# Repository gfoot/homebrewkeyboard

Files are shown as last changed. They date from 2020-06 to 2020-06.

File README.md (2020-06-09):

# George's homebrew keyboard

Schematics, board layouts, and code for adding a homebrew keyboard to your electronics projects

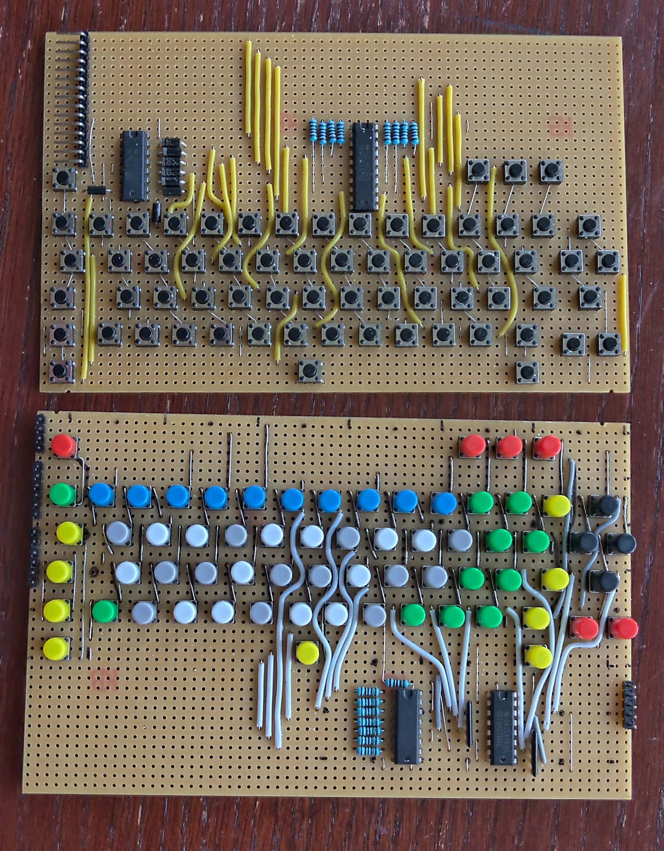
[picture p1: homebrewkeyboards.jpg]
Photograph of assembled boards


This one uses a parallel interface, ideal for connecting directly to the address and data bus of something like a 6502.

I also have one with a serial interface, more tailored for Arduino - let me know if you're interested and I'll publish it as a separate project.

# Schematic

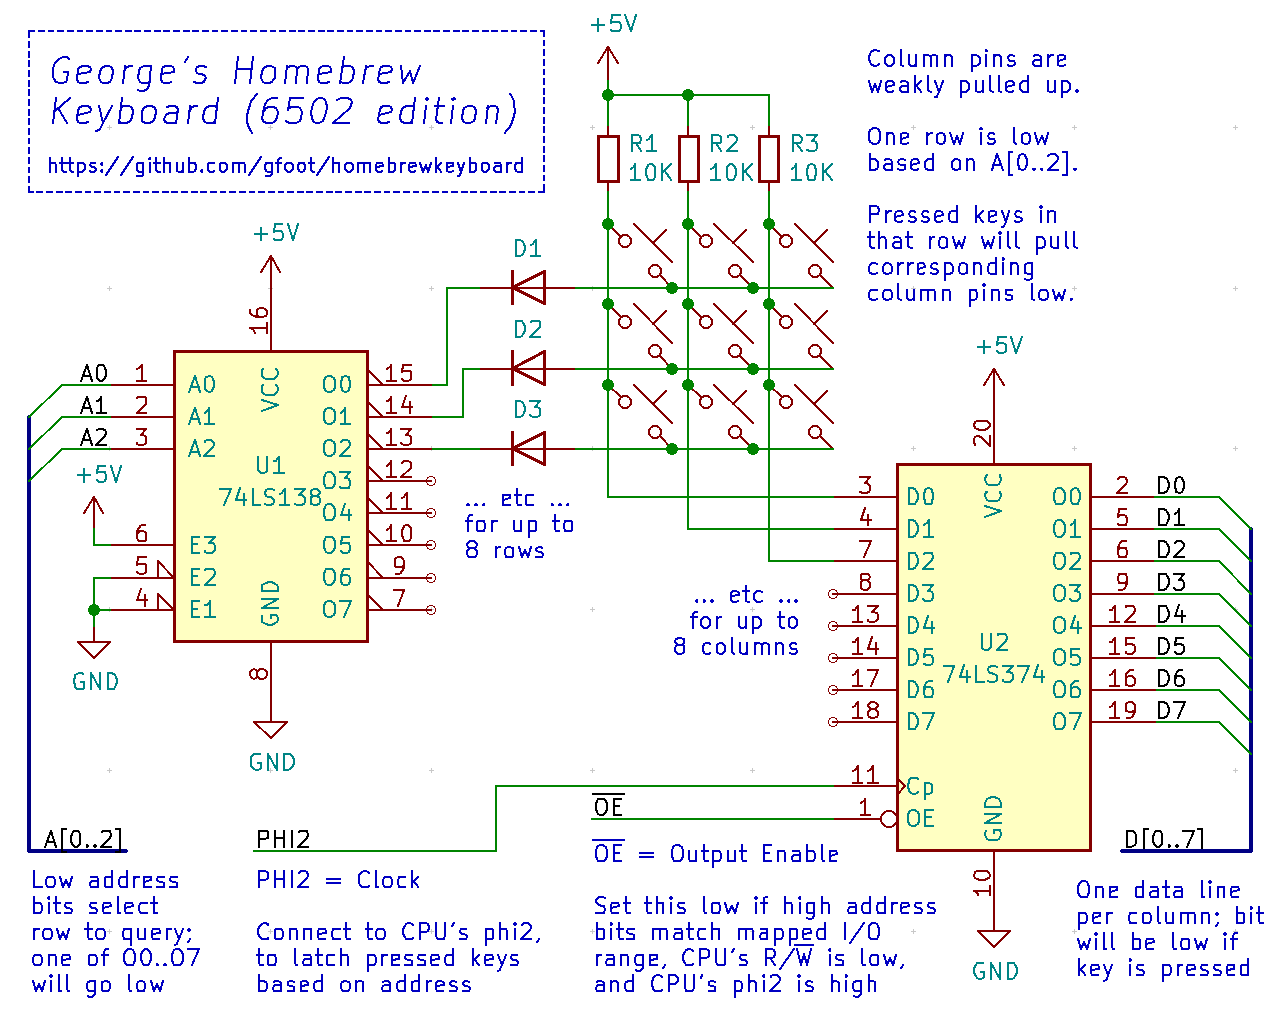
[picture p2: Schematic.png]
Annotated schematic of George's Homebrew Keyboard (6502 edition)


# Bill of materials

* 8x resistor, 10k or thereabouts
* 8x diode, e.g. 1N4007
* 66x 4-pin push-switch with 5.08mmx5.08mm (0.2") pin pitch
* 1x 74LS138 address decoder
* 1x 74LS374 8-bit latch/register with tri-state outputs
* 1x 15-pin header for connecting wires (ideally horizontal, with bent pins)
* Veroboard - 39 tracks of 64 holes, or larger

# General operation

Connect:
* A0..A2 to the CPU's address bus
* D0..7 to the CPU's data bus
* PHI2 to the CPU's phi2 clock signal (the same one you use to time access to RAM, ROM, etc)
* ~OE to a combination of phi2, R/~W, and some address decoding logic

~OE needs to be kept high unless all of the following are true:
* phi2 is high (indicating the bus is active)
* R/~W is low (indicating a write cycle)
* high address pins map to keyboard I/O region

For the last one, my own 6502 computer simply uses an LS138 fed by the top three address lines, and one of the LS138's outputs drives this logic - the same way I generate chip-select signals for other memory-mapped parts of the computer.

Then the CPU can simply read from the mapped addresses.  The lowest address - for example, $a000 - corresponds to one "row" of keys; each bit is 1 if the corresponding key is not pressed, and 0 if it is pressed.  The next address, $a001, corresponds to the next "row", up to the final row at $a007.  The word "row" refers to the schematic, not the physical layout.

As an example, the shift keys correspond to bit 1 of $a000; the ctrl keys correspond to bit 3.  I think bit 0 is Esc, and bit 2 is the space bar.  $a001's bit 0 corresponds to the tilde/backtick key; bit 1 is probably tab or Q; bit 2 is A; and so on.  The exact layout was tweaked to make it easier to build on veroboard, while also ensuring that rollover works well with modifier keys in particular; as usual for this sort of thing, you need to do a lot more translation in software.

See the [kbd module](code/kbd.6502) which contains a full table of characters by row/column.

# Sample code

See [sample code](code/SampleCode.md) and [kbd module](code/kbd.6502).

# Board layout

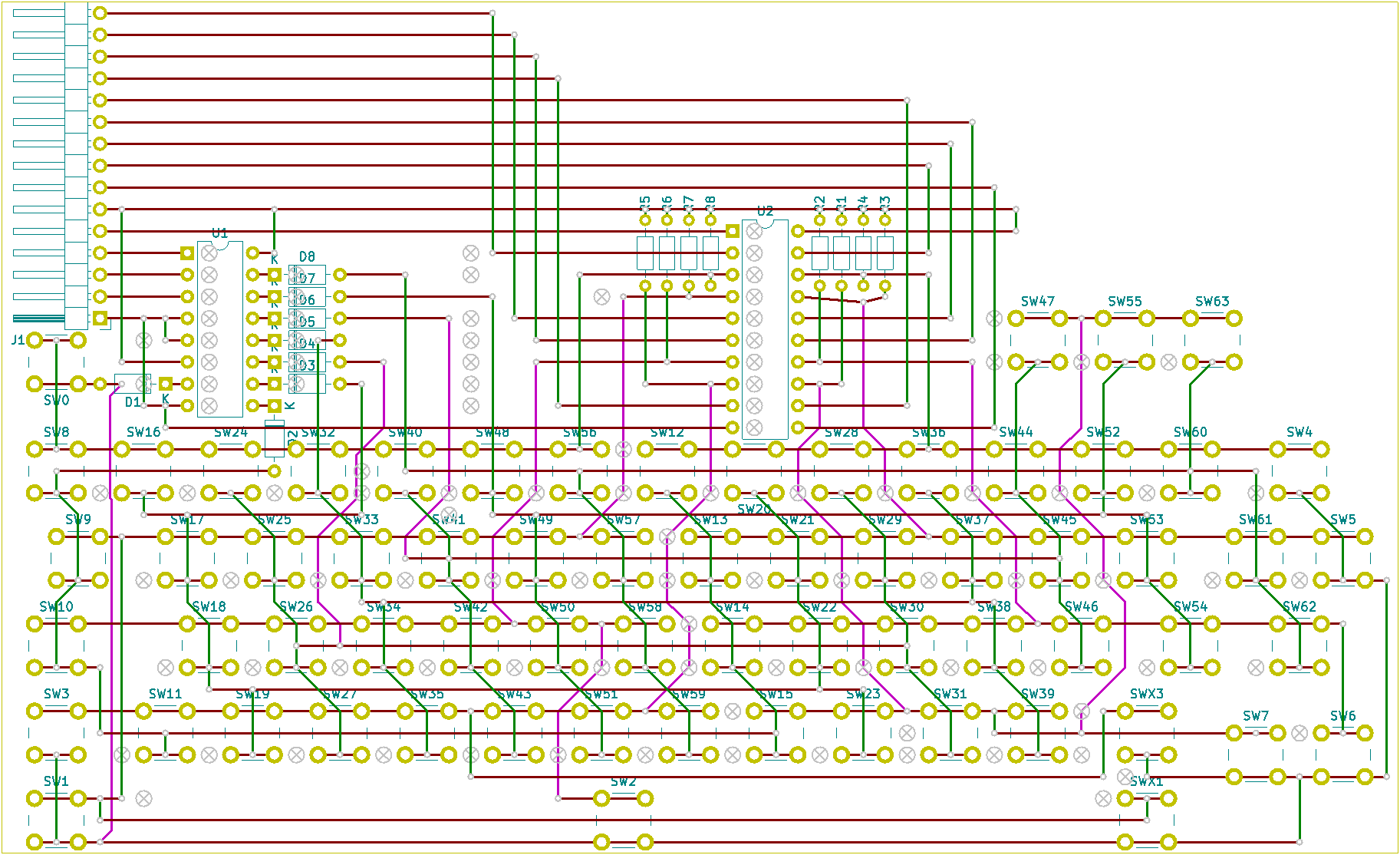
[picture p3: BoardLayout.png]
Physical board layout


The board layout shows the physical layout of the components.  The veroboard tracks run horizontally, and - where they are used - they are shown in dark red.  Green traces indicate fairly short links, mostly made with bare wire.  Pink traces indicate longer insulated wire links.  The (X) marks show where you need to break the existing veroboard tracks.

Some connections occur underneath switches, or pass entirely under a switch.  This doesn't always work well in practice, and I ended up routing some wires differently to this diagram.  It depends on the thickness of the wire and the physical shape of your switches.

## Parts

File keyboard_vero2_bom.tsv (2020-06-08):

Reference | Quantity | Value | Footprint | Datasheet
D1 D2 D3 D4 D5 D6 D7 D8 | 8 | 1K | Diode_THT:D_DO-35_SOD27_P7.62mm_Horizontal | ~
J1 | 1 | Conn_01x15_Male | Connector_PinHeader_2.54mm:PinHeader_1x15_P2.54mm_Horizontal | ~
R1 R2 R3 R4 R5 R6 R7 R8 | 8 | 10K | Resistor_THT:R_Axial_DIN0204_L3.6mm_D1.6mm_P7.62mm_Horizontal | ~
SW0 SW1 SW2 SW3 SW4 SW5 SW6 SW7 SW8 SW9 SW10 SW11 SW12 SW13 SW14 SW15 SW16 SW17 SW18 SW19 SW20 SW21 SW22 SW23 SW24 SW25 SW26 SW27 SW28 SW29 SW30 SW31 SW32 SW33 SW34 SW35 SW36 SW37 SW38 SW39 SW40 SW41 SW42 SW43 SW44 SW45 SW46 SW47 SW48 SW49 SW50 SW51 SW52 SW53 SW54 SW55 SW56 SW57 SW58 SW59 SW60 SW61 SW62 SW63 SWX1 SWX3 | 66 | SW_Push_45deg | keyboard_vero2:SW_PUSH_6mm | ~
U1 | 1 | 74LS138 | Package_DIP:DIP-16_W7.62mm | http://www.ti.com/lit/gpn/sn74LS138
U2 | 1 | 74LS374 | Package_DIP:DIP-20_W7.62mm | http://www.ti.com/lit/gpn/sn74LS374

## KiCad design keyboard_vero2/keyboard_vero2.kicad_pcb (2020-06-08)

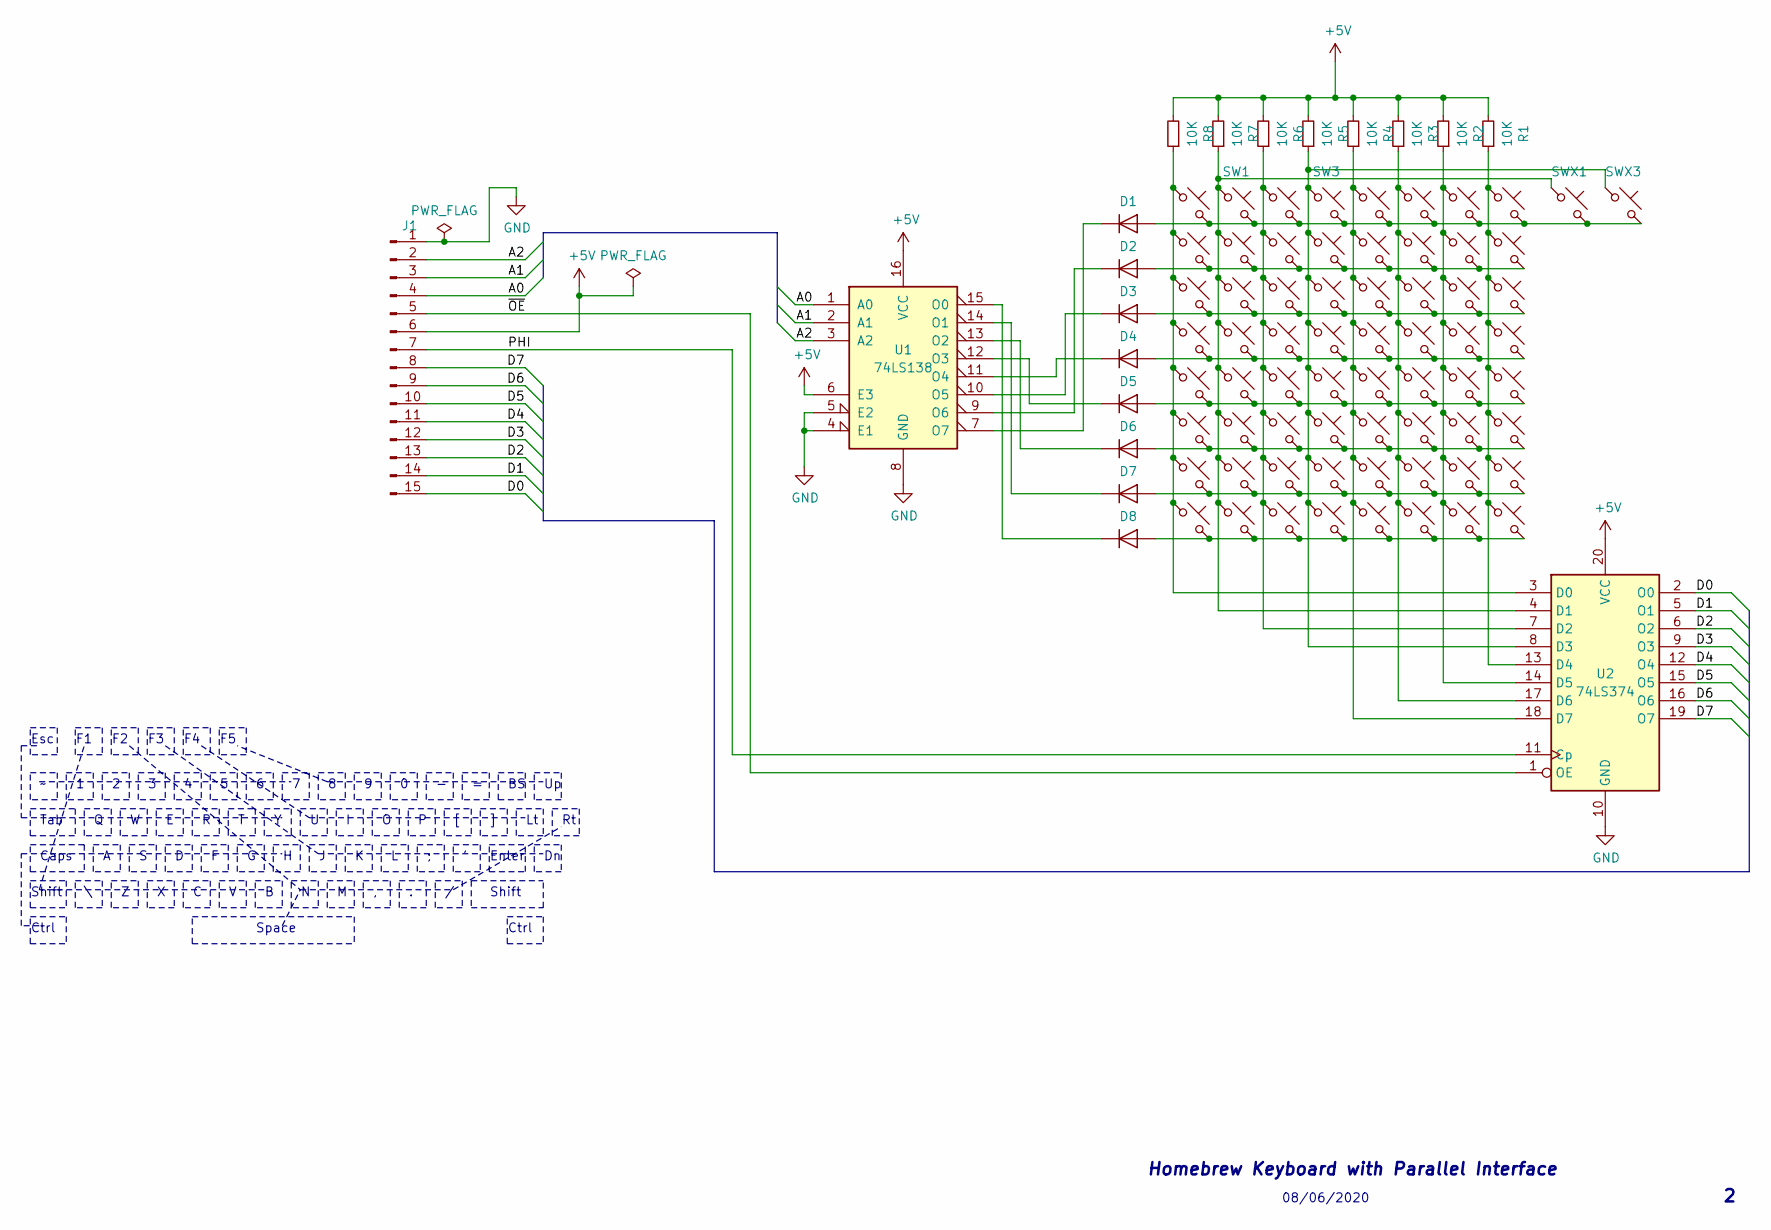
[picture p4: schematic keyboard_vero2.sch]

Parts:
D1, D2, D3, D4, D5, D6, D7, D8: 1K; D_DO-35_SOD27_P7.62mm_Horizontal
J1: Conn_01x15_Male; PinHeader_1x15_P2.54mm_Horizontal
R1, R2, R3, R4, R5, R6, R7, R8: 10K; R_Axial_DIN0204_L3.6mm_D1.6mm_P7.62mm_Horizontal
SW0, SW1, SW2, SW3, SW4, SW5, SW6, SW7, SW8, SW9, SW10, SW11, SW12, SW13, SW14, SW15, SW16, SW17, SW18, SW19, SW20, SW21, SW22, SW23, SW24, SW25, SW26, SW27, SW28, SW29, SW30, SW31, SW32, SW33, SW34, SW35, SW36, SW37, SW38, SW39, SW40, SW41, SW42, SW43, SW44, SW45, SW46, SW47, SW48, SW49, SW50, SW51, SW52, SW53, SW54, SW55, SW56, SW57, SW58, SW59, SW60, SW61, SW62, SW63: SW_Push_45deg; SW_PUSH_6mm
SWX1, SWX3: SW_Push_45deg; SW_PUSH_6mm
U1: 74LS138; DIP-16_W7.62mm
U2: 74LS374; DIP-20_W7.62mm

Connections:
+5V: J1.6, R1.2, R2.2, R3.2, R4.2, R5.2, R6.2, R7.2, R8.2, U1.6 (E3), U1.16 (VCC), U2.20 (VCC)
/A0: J1.4, U1.1 (A0)
/A1: J1.3, U1.2 (A1)
/A2: J1.2, U1.3 (A2)
/D0: J1.15, U2.2 (O0)
/D1: J1.14, U2.5 (O1)
/D2: J1.13, U2.6 (O2)
/D3: J1.12, U2.9 (O3)
/D4: J1.11, U2.12 (O4)
/D5: J1.10, U2.15 (O5)
/D6: J1.9, U2.16 (O6)
/D7: J1.8, U2.19 (O7)
/PHI: J1.7, U2.11 (Cp)
/~OE: J1.5, U2.1 (OE)
GND: J1.1, U1.4 (E1), U1.5 (E2), U1.8 (GND), U2.10 (GND)
unnamed: D1.1 (K), U1.7 (O7)
unnamed: D1.2 (A), SW0.2, SW1.2, SW2.2, SW3.2, SW4.2, SW5.2, SW6.2, SW7.2, SWX1.2, SWX3.2
unnamed: D2.1 (K), U1.9 (O6)
unnamed: D2.2 (A), SW8.2, SW9.2, SW10.2, SW11.2, SW12.2, SW13.2, SW14.2, SW15.2
unnamed: D3.1 (K), U1.10 (O5)
unnamed: D3.2 (A), SW16.2, SW17.2, SW18.2, SW19.2, SW20.2, SW21.2, SW22.2, SW23.2
unnamed: D4.1 (K), U1.11 (O4)
unnamed: D4.2 (A), SW24.2, SW25.2, SW26.2, SW27.2, SW28.2, SW29.2, SW30.2, SW31.2
unnamed: D5.1 (K), U1.12 (O3)
unnamed: D5.2 (A), SW32.2, SW33.2, SW34.2, SW35.2, SW36.2, SW37.2, SW38.2, SW39.2
unnamed: D6.1 (K), U1.13 (O2)
unnamed: D6.2 (A), SW40.2, SW41.2, SW42.2, SW43.2, SW44.2, SW45.2, SW46.2, SW47.2
unnamed: D7.1 (K), U1.14 (O1)
unnamed: D7.2 (A), SW48.2, SW49.2, SW50.2, SW51.2, SW52.2, SW53.2, SW54.2, SW55.2
unnamed: D8.1 (K), U1.15 (O0)
unnamed: D8.2 (A), SW56.2, SW57.2, SW58.2, SW59.2, SW60.2, SW61.2, SW62.2, SW63.2
unnamed: R1.1, SW7.1, SW15.1, SW23.1, SW31.1, SW39.1, SW47.1, SW55.1, SW63.1, U2.13 (D4)
unnamed: R2.1, SW6.1, SW14.1, SW22.1, SW30.1, SW38.1, SW46.1, SW54.1, SW62.1, U2.14 (D5)
unnamed: R3.1, SW5.1, SW13.1, SW21.1, SW29.1, SW37.1, SW45.1, SW53.1, SW61.1, U2.17 (D6)
unnamed: R4.1, SW4.1, SW12.1, SW20.1, SW28.1, SW36.1, SW44.1, SW52.1, SW60.1, U2.18 (D7)
unnamed: R5.1, SW3.1, SW11.1, SW19.1, SW27.1, SW35.1, SW43.1, SW51.1, SW59.1, SWX3.1, U2.8 (D3)
unnamed: R6.1, SW2.1, SW10.1, SW18.1, SW26.1, SW34.1, SW42.1, SW50.1, SW58.1, U2.7 (D2)
unnamed: R7.1, SW1.1, SW9.1, SW17.1, SW25.1, SW33.1, SW41.1, SW49.1, SW57.1, SWX1.1, U2.4 (D1)
unnamed: R8.1, SW0.1, SW8.1, SW16.1, SW24.1, SW32.1, SW40.1, SW48.1, SW56.1, U2.3 (D0)

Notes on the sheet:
Shift
Tab
Caps
Ctrl
Space
Esc
Enter
Homebrew Keyboard with Parallel Interface
08/06/2020

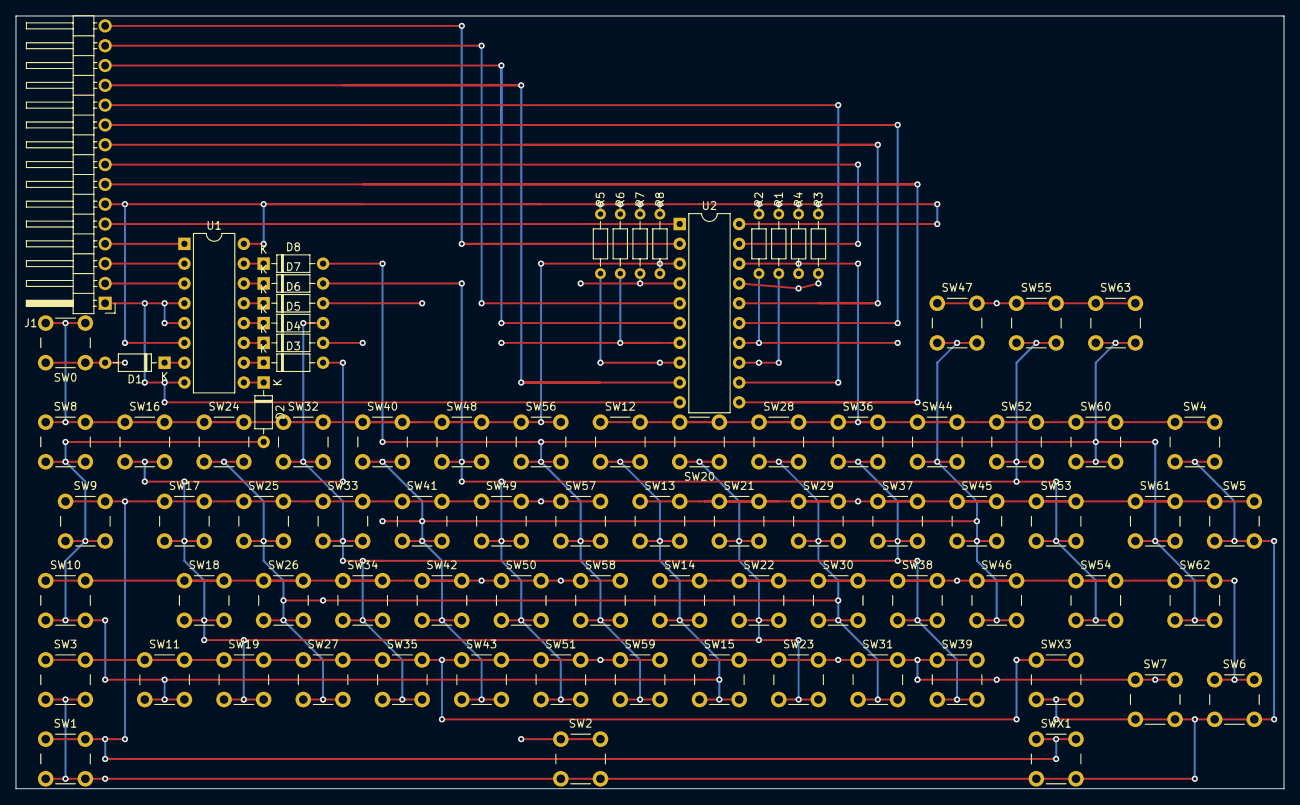
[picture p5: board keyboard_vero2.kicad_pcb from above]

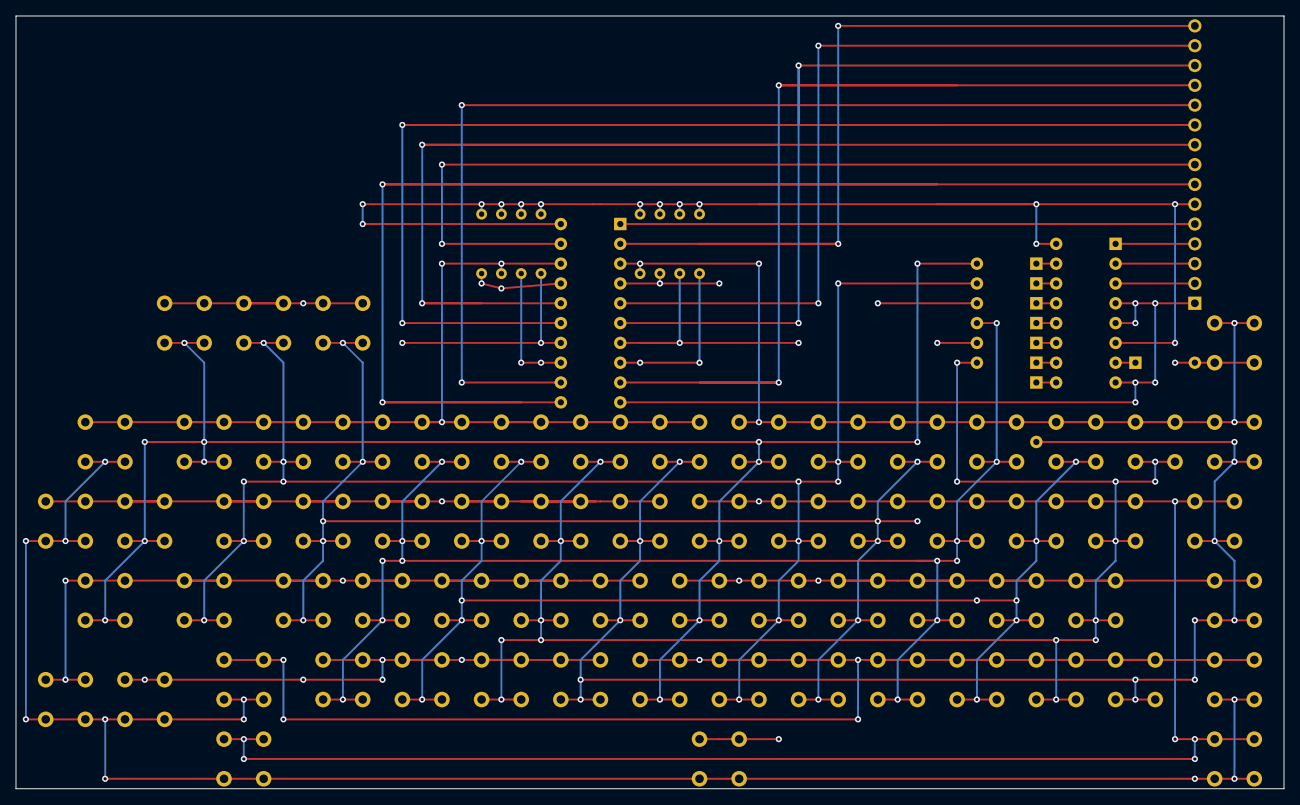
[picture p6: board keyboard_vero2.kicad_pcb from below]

Board: 4 copper layers, 162.6 x 99.1 mm, 85 parts (85 on the bottom side), 39 nets.

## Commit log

2020-06-08 Initial checkin - not quite up-to-date
    [keyboard_vero2.kicad_pcb, keyboard_vero2.sch]
2020-06-08 Updated schematic to match final build; created BOM
    [keyboard_vero2.kicad_pcb, keyboard_vero2.sch, keyboard_vero2_bom.tsv]
2020-06-08 Add annotated schematic to README.md
    [annotated.sch]
2020-06-08 Add photo of assembled boards
2020-06-08 Unlink ~OE from LS138's enable input
    [keyboard_vero2.kicad_pcb, keyboard_vero2.sch]
2020-06-08 Add board layout image
2020-06-08 Rename to csv in case it works better in github
    [keyboard_vero2_bom.csv]
2020-06-08 Rename it back and convert commas to tabs
    [keyboard_vero2_bom.csv, keyboard_vero2_bom.tsv]
2020-06-09 Add sample code and library code; move KiCad stuff into a subdirectory
    [annotated.sch, keyboard_vero2.kicad_pcb, keyboard_vero2.sch]
2020-06-09 Add references to sample code
